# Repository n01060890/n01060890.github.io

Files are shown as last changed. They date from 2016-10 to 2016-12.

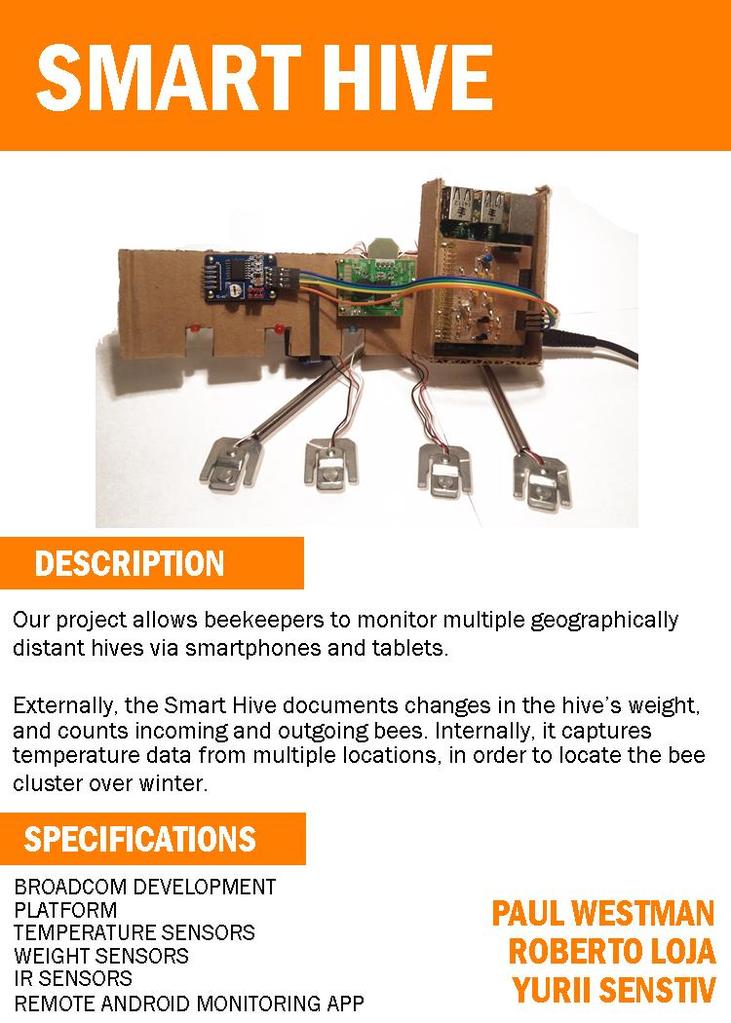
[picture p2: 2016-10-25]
media/placard.jpg

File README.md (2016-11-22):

# Smart Hive

Our project allows beekeepers to monitor multiple geographically distant hives via smartphones and tablets.

Externally, the Smart Hive documents changes in the hive's weight, and counts incoming and outgoing bees.
Internally, it captures multiple temperature and humidity data, in order to locate the bee cluster over the winter.

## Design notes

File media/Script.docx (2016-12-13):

30 Second Script

Name: Yurii Sentsiv

Project: Smart Hive

Date: December 13, 2016

In my project, Smart Hive, I was asked to implement features, that will give an ability to track internal temperature and humidity, as well as location of the bee cluster in the winter. With the help of multiple temperature and humidity sensors DHT11, and python program, I can retrieve the data. Further, the raw data is being processed, and is displayed graphically on the web server.

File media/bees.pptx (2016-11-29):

## Smart Hive

Yurii sentsiv
Ceng 317

## Introduction (Proposal)

- In the start of the semester my new team members and myself choose to work with bees, particularly create a monitoring system to help bee keepers in Humber College understand better and be able to see what is happening with the hives remotely.
- As have been discussed with bee keepers previously, it was clear that they were lacking the ability to have temperature/humidity status of the hive, as well as, having an ability to locate the bee cluster in the hive during the winter.
- In order to solve this problem I am using regular temperature & humidity sensors DHT11 in order to have real time readings, as well as, with help of the algorithm, to located cluster inside the hive, depending on the temperature readings.

## Introduction (Proposal)

- For more accurate readings I use 4 DHT11s on each side of the hive. Using the python script and Adafruit library I’m able to simultaneously read the data from all of the sensors using GPIO pins. Also, having the sensor hat, that was built by us, I have an LED, which I use to indicate when the data readings are happening.
- In order to have automated readings from the sensors, I use crontab, which is UNIX command that schedules the prewritten scripts.
- To have data visually presented, I’m using the javascript’s dygraph library to visually present the fluctuation of the temperature & humidity reading through the time.
- Also, to present the location of the cluster I use regular javascript’s canvas, where I draw the cluster, with the coordinates calculated with my algorithm.

## Budget

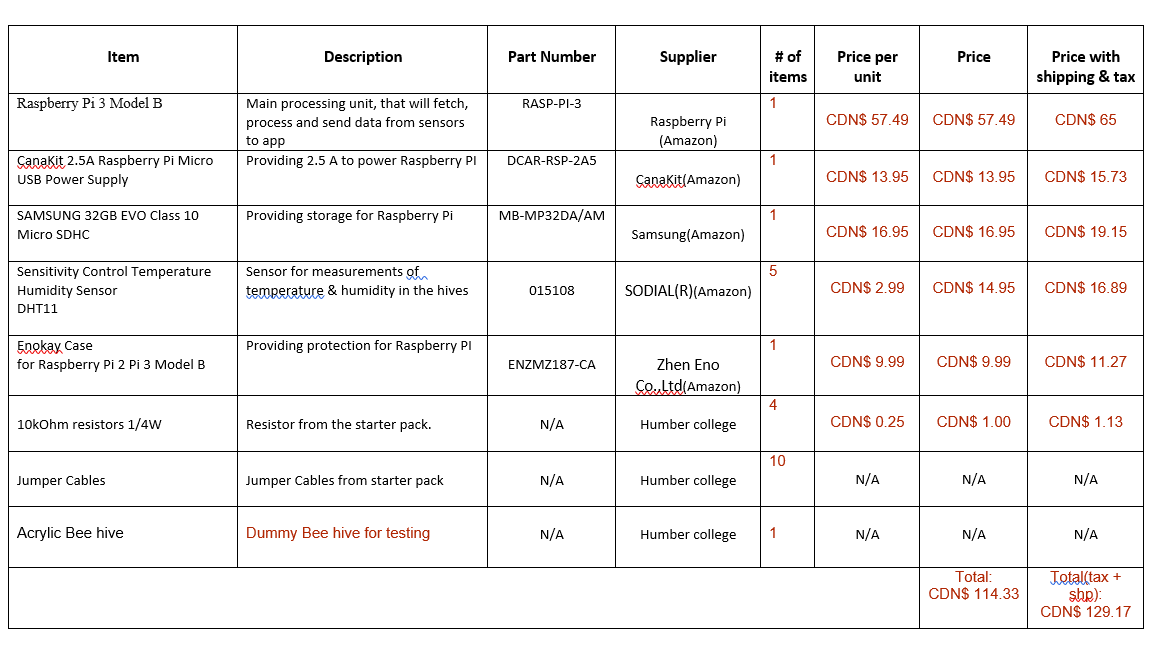
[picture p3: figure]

## Schedule : hardware

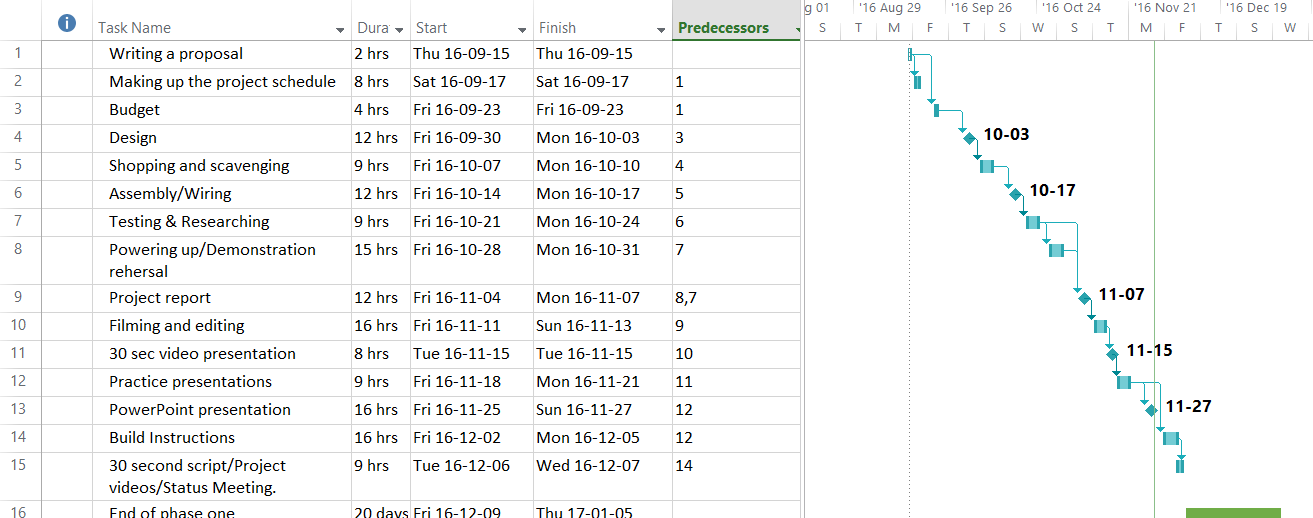
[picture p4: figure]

## Schedule : integration

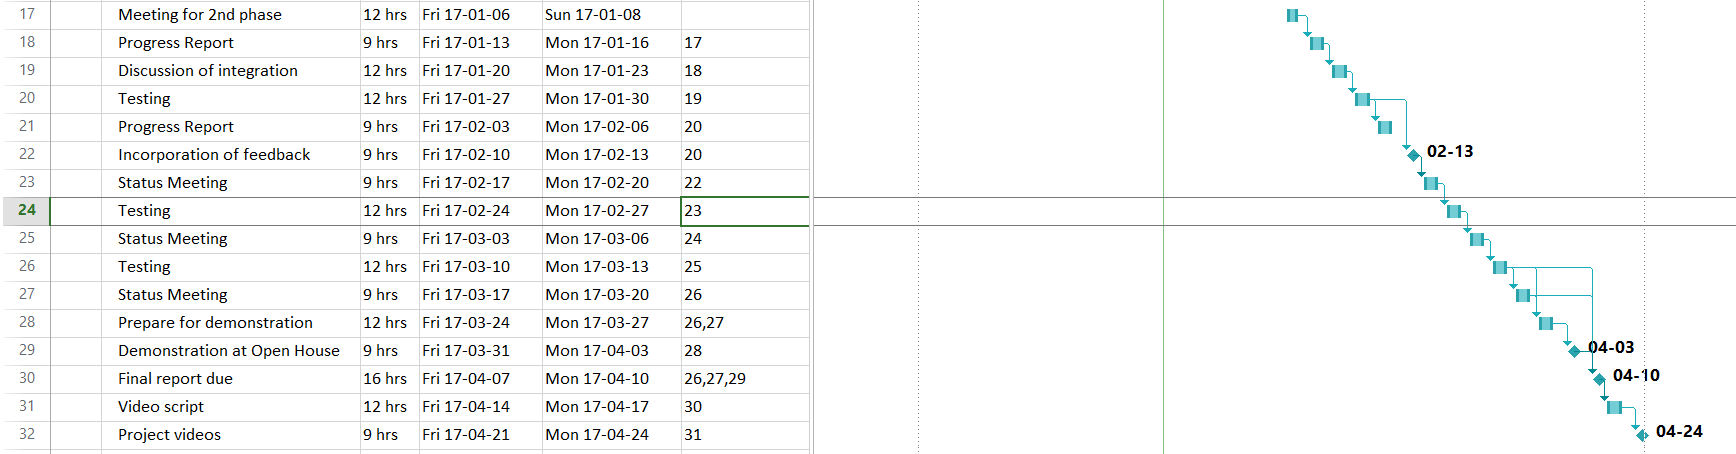
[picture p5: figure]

## Course knowledge utilized from previous courses

In the Computer Engineering Technology program we have learned about the following topics from the respective relevant courses:
- Construction of circuits from CENG 215 Digital And Interfacing Systems,
- Rapid application development and Gantt charts from CENG 216 Intro to Software Engineering,
- Micro computing from CENG 252 Embedded Systems,
- SQL from CENG 254 Database With Java,
- Web access of databases from CENG 256 Internet Scripting; and,
- Wireless protocols such as 802.11 from TECH152 Telecom Networks.

## Thank you!

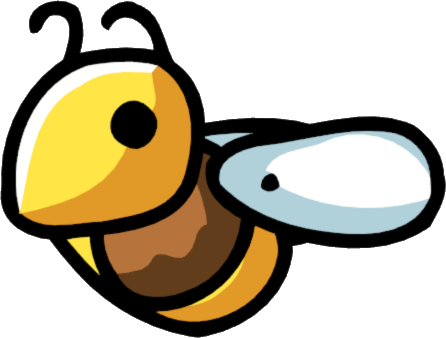
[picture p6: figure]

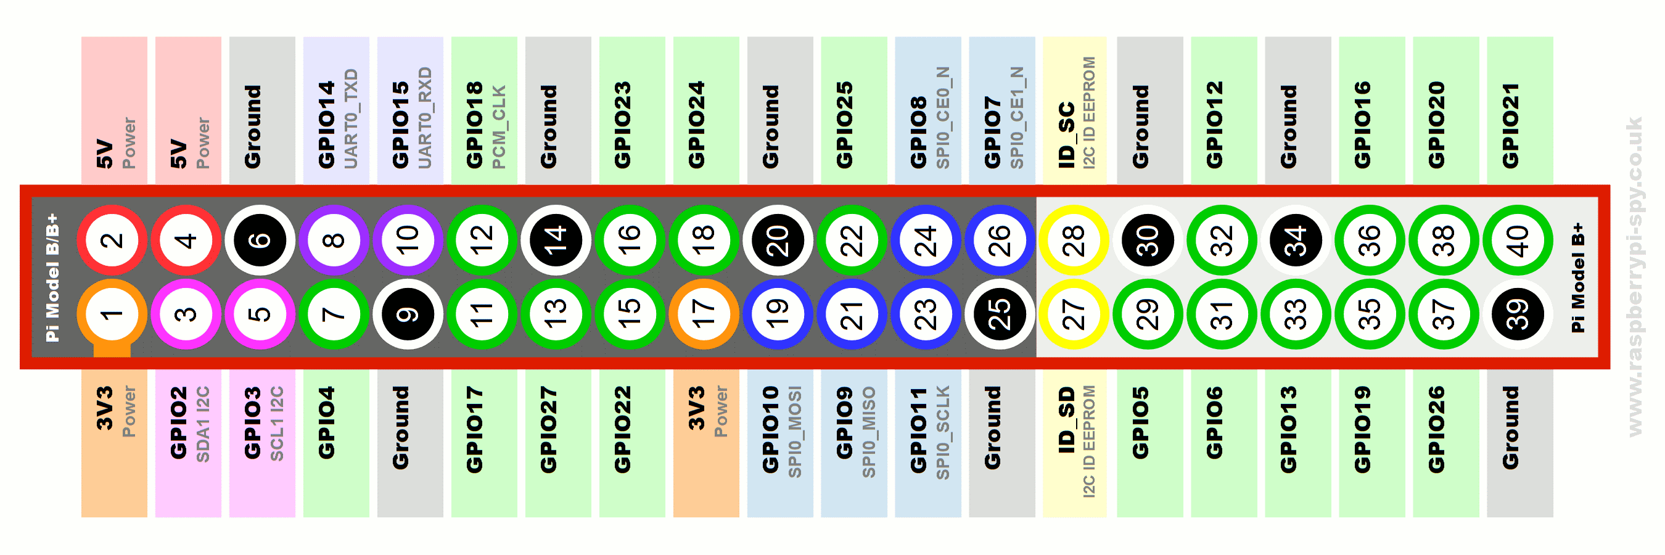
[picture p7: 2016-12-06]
media/rasp_pinout.png

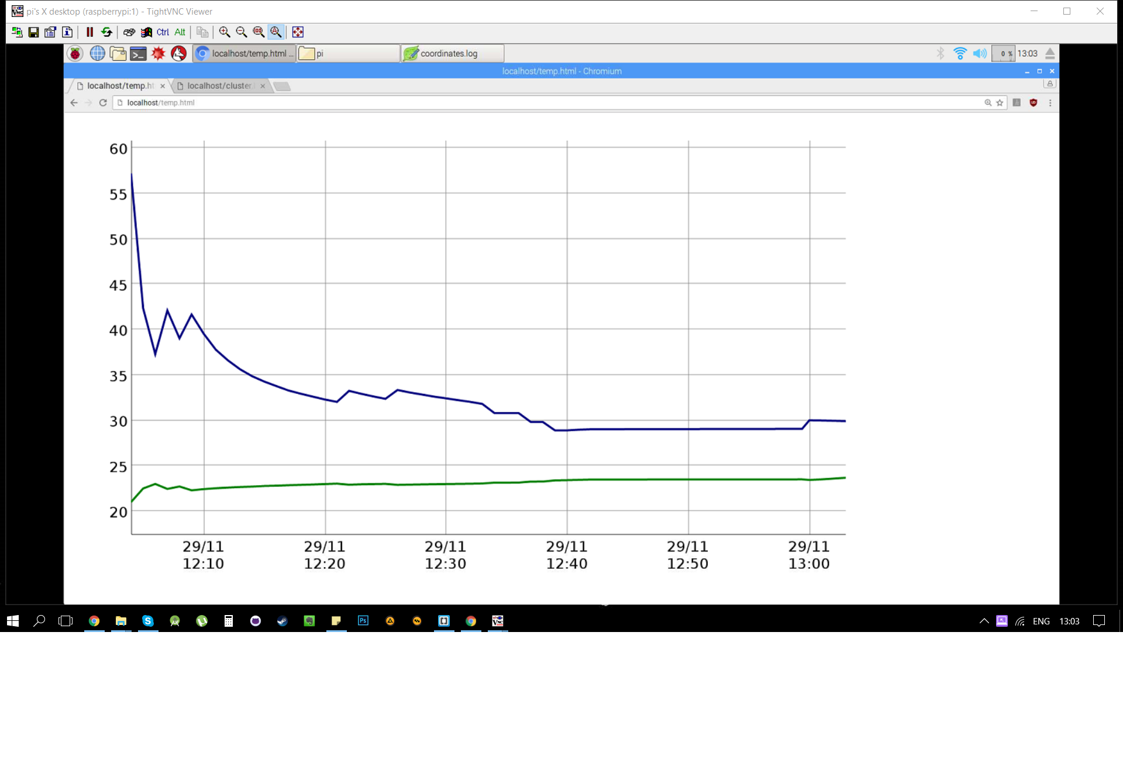
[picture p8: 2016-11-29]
media/graph.png

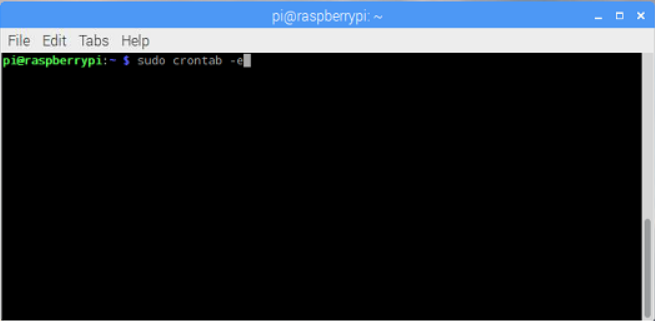
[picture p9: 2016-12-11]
media/crontab-call.png

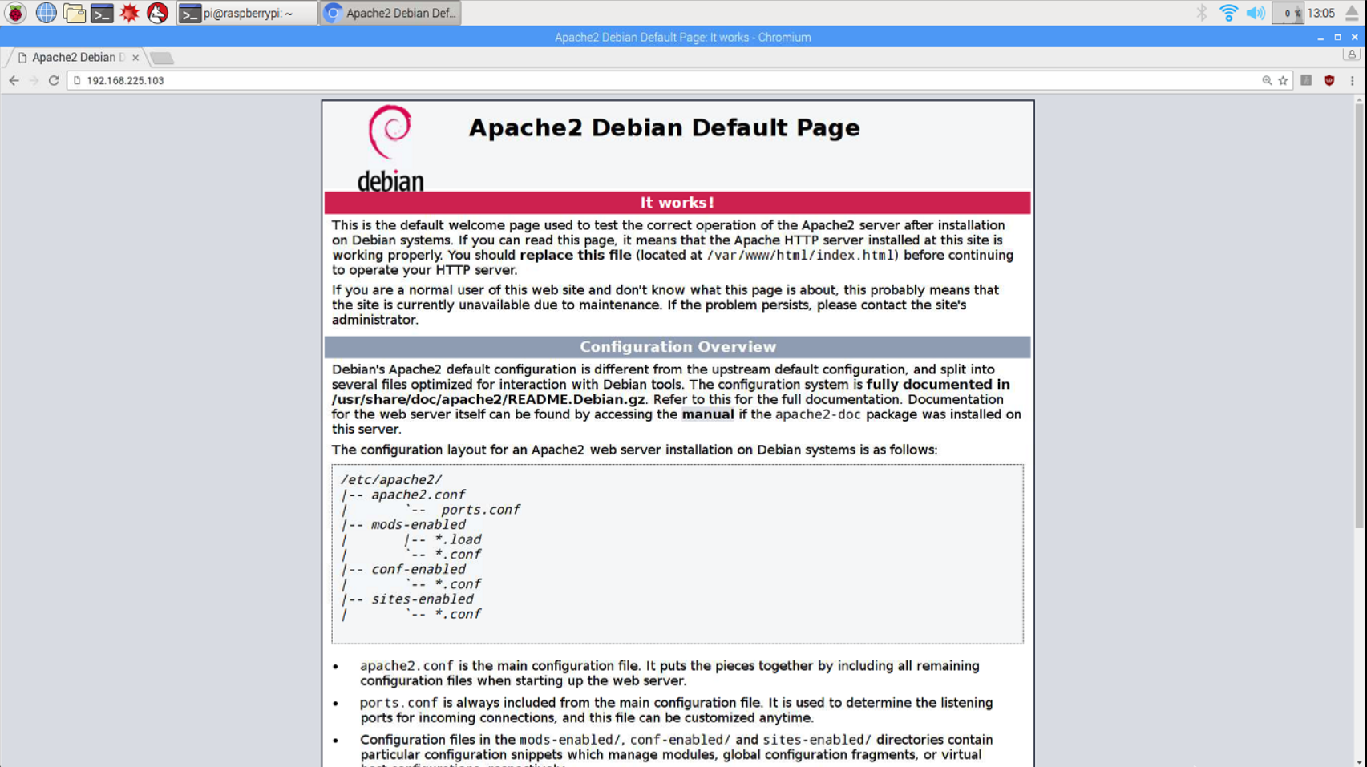
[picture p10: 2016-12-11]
media/apache.png

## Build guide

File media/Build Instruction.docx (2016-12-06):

Smart Hive

Build Log

By Yurii Sentsiv

Introduction

The project that I was working is the part of the automated hive monitoring system, called Smart Hive. My group, called “2bee || !2bee”, consisting of Paul Westman, Roberto Loja, and Yurii Sentsiv(myself) designed a prototype of Smart Hive, that would gather different information on hives, where our smart system would be installed. Specifically, I was working on temperature and humidity monitoring, as well as bee cluster detection. Here I would like to share my achievement, as well as my progress, so everyone could rebuild my project.

System Diagram

The concept of our project is to give an ability remotely track the status of the hives. It will be achieved to fetching the sensor readings from the hives, that would be attached to Raspberry Pi, process them, save in the database, and then deliver to customers in the user-friendly Android application representation.

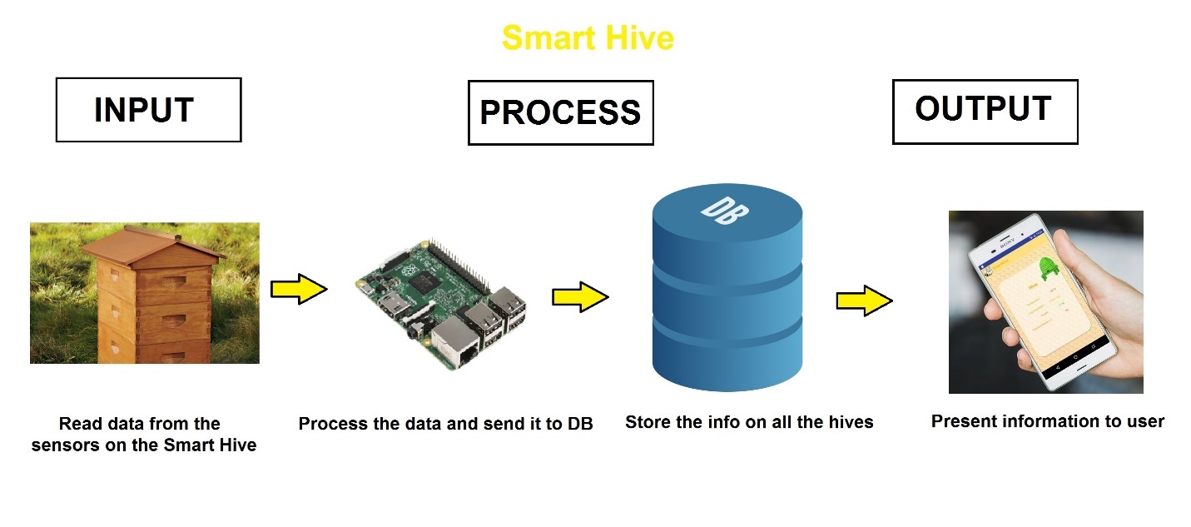
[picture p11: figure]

Budget of the Project

As it was decided in my group, different parts of the project would be covered by different group member, as it will result it total group budget, decreasing total cost, as well as on time of research given to different parts of the Smart Hive project. I ended up using Raspberry PI, DHT11 temperature/humidity sensors, as well as resistors, jumper cables, electrical tape, soldering iron, Humber PCB Components Kit, and making laser cut dummy hive. Fortunately, most of the parts I obtained in kit, that I used in my previous courses, as well as laser cut hive, that to presented to me for free. Following is my budget:


Time Commitment

At the start of our semester we created schedule for better time management, and tried to follow all the milestones in time. If exclude all the progress reports, meetings and designing, here are the key point that need to be done, in order for anyone to replicate the project:

Milestone Time required

Ordering parts May vary where you order them, but if you would choose to guy them in the Canada Robotix, you can get them in few hours.

Laser Cutting the acrylic hive 10 minutes

Printing PCB 1 day

Soldering & testing PCB 3 hours

Soldering the sensor to wires and resistor 30 minutes

Attaching the sensor on the hive 5 minutes

Attaching the sensors on the PI’s GPIOs 10 minutes

Raspberry Pi 3 Setup 2 hours

Loading the code and executing it 10 minutes

Unit testing 30 minutes

Setting up the Apache server 30 minutes

Loading the HTML & JavaScript

For data representation 10 minutes

The whole process should take around 2-3 days, if the appropriate tools are accessible (PCB print, laser cutter, soldering station). For myself the whole process was split into 15 weeks, where every week I committed few hours, in order to be on track and be able to finish everything by the week 15. Attached is the original project schedule:

Mechanical Assembly

Step 1:

Create the casing for the dummy hive, in my case I was using Corel Draw. For our laser cutting machine, specific colours specified the inside cut → red, outside cut → green, engraving → black. Attached is my casing that consist of 4 part, which I have glued afterwards.

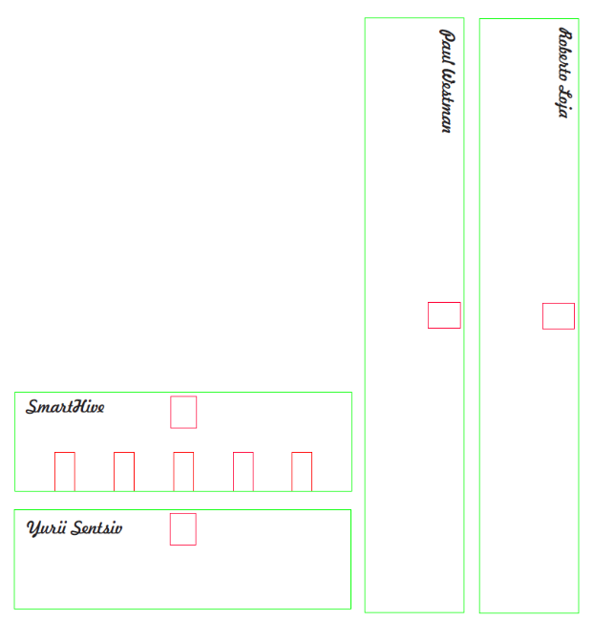
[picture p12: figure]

Step 2:

In my case, because I bought DHT11 sensors without PCB board with resistors, that sensor needs, I simply soldered the resistors to the sensors between Power(Pin1) & Data(Pin2), so I didn’t need to use the breadboard, which was used in development purposes.

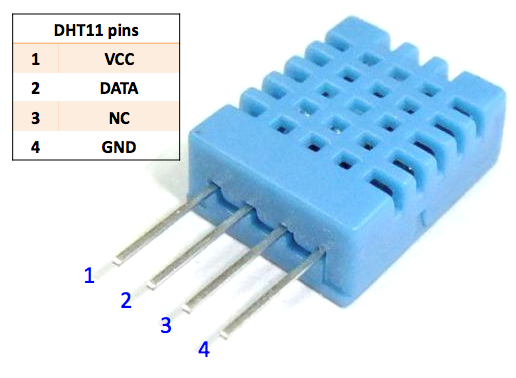
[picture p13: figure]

If it is possible, I recommend you to buy the one with the PCB.

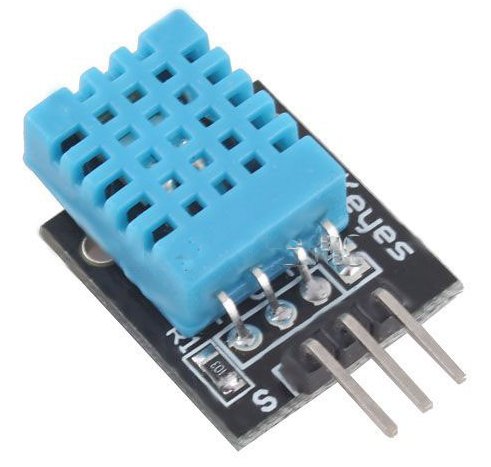
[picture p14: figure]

Step 3:

In this next step, we will be connecting the sensors to the Raspberry Pi. In my case I was struggling to connect multiple sensors, as in the most example of code, this particular sensor was using GPIO4, which is also GPCLK0. All other GPIO pins would not work with this particular code in C, nor with Python equivalent:

#include <wiringPi.h>

#include <stdio.h>

#include <stdlib.h>

#include <stdint.h>

#define MAXTIMINGS 85

#define DHTPIN 7

int dht11_dat[5] = { 0, 0, 0, 0, 0 };

void read_dht11_dat()

{

uint8_t laststate = HIGH;

uint8_t counter = 0;

uint8_t j = 0, i;

float f;

dht11_dat[0] = dht11_dat[1] = dht11_dat[2] = dht11_dat[3] = dht11_dat[4] = 0;

pinMode( DHTPIN, OUTPUT );

digitalWrite( DHTPIN, LOW );

delay( 18 );

digitalWrite( DHTPIN, HIGH );

delayMicroseconds( 40 );

pinMode( DHTPIN, INPUT );

for ( i = 0; i < MAXTIMINGS; i++ )

{

counter = 0;

while ( digitalRead( DHTPIN ) == laststate )

{

counter++;

delayMicroseconds( 1 );

if ( counter == 255 )

{

break;

}

}

laststate = digitalRead( DHTPIN );

if ( counter == 255 )

break;

if ( (i >= 4) && (i % 2 == 0) )

{

dht11_dat[j / 8] <<= 1;

if ( counter > 16 )

dht11_dat[j / 8] |= 1;

j++;

}

}

if ( (j >= 40) &&

(dht11_dat[4] == ( (dht11_dat[0] + dht11_dat[1] + dht11_dat[2] + dht11_dat[3]) & 0xFF) ) )

{

f = dht11_dat[2] * 9. / 5. + 32;

printf( "Humidity = %d.%d %% Temperature = %d.%d C (%.1f F)\n",

dht11_dat[0], dht11_dat[1], dht11_dat[2], dht11_dat[3], f );

}else {

printf( "Data not good, skip\n" );

}

}

int main( void )

{

printf( "Raspberry Pi wiringPi DHT11 Temperature test program\n" );

if ( wiringPiSetup() == -1 )

exit( 1 );

while ( 1 )

{

read_dht11_dat();

delay( 1000 );

}

return(0);

}

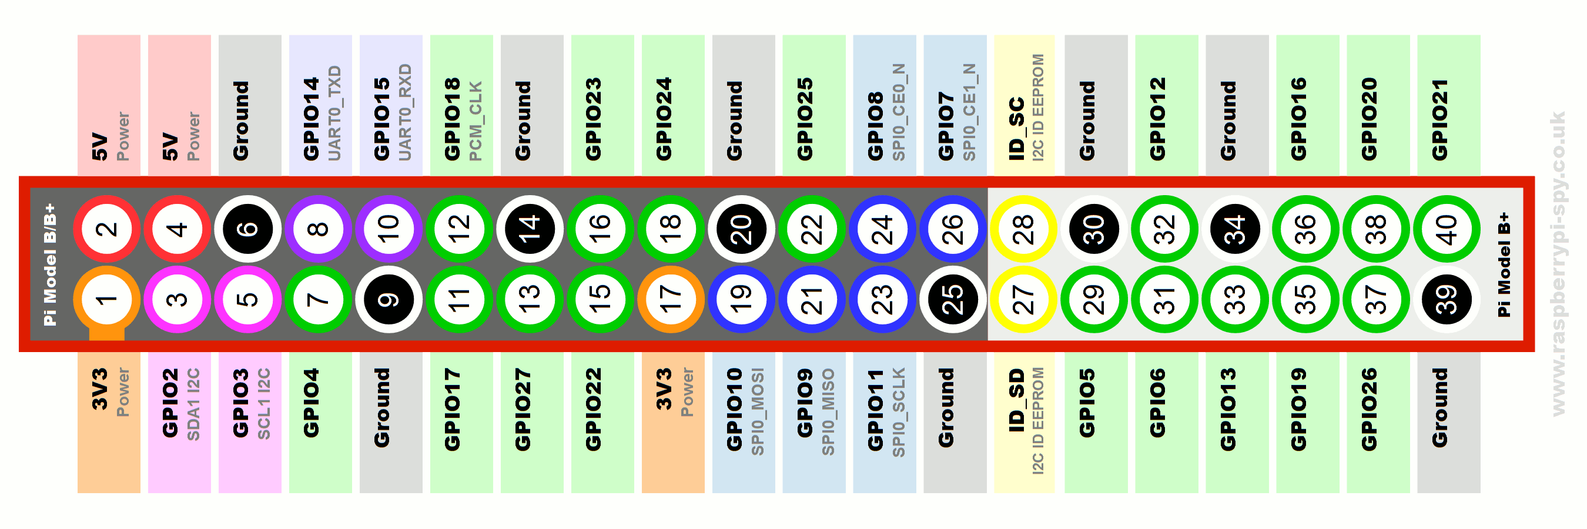
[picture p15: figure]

Instead I found Adafruit library that handles the DHT11 on the regular GPIO pins, so consequently I used GPIO22 – GPIO25 for 4 sensors. → https://github.com/adafruit/Adafruit_Python_DHT . Instruction on install are in the README of that Git project.

The following is the wiring that I used to connect my DHT11 to Raspberry PI’s GPIO 22-25 pins.

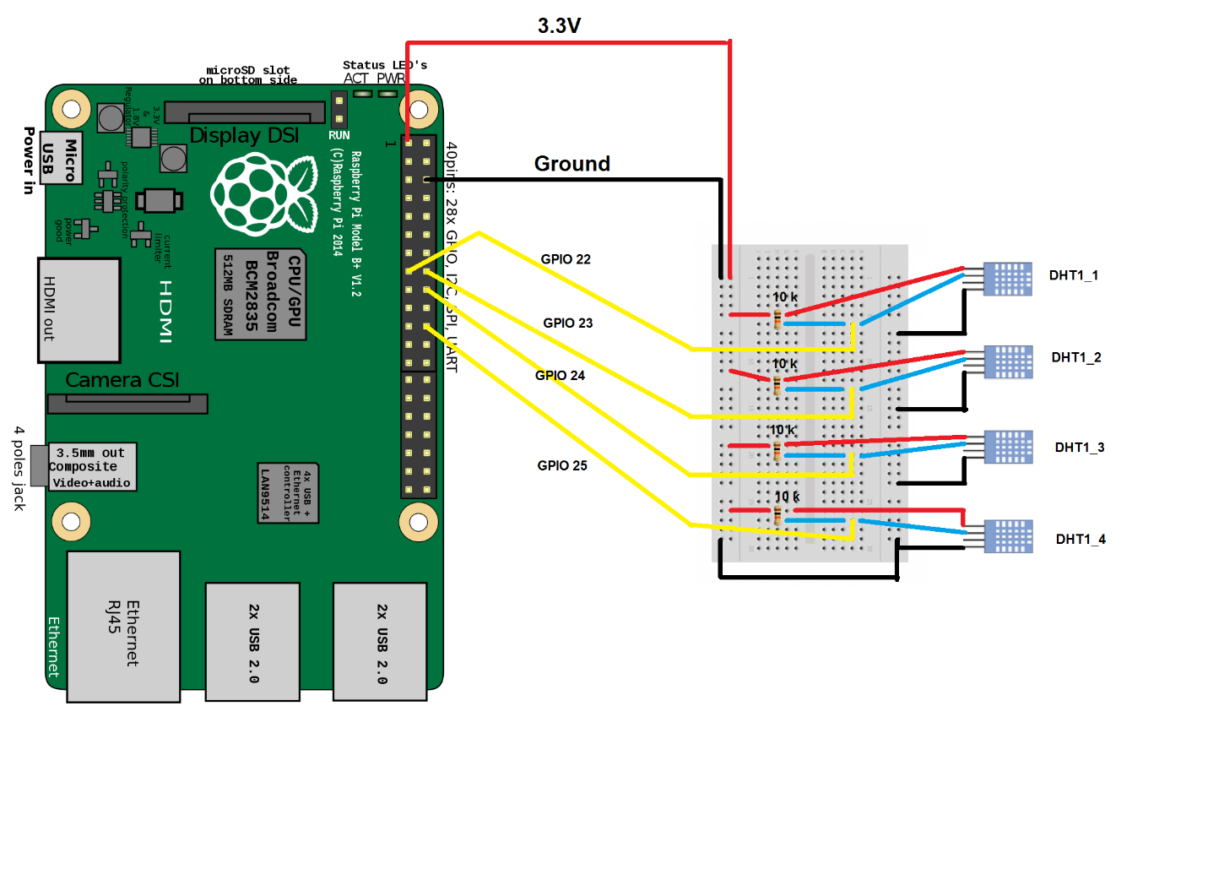
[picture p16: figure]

As I said previously, you don’t need to have a resistor, if you’ll get the sensor with the PCS. In my case had it soldered and isolated with the electrical tape.

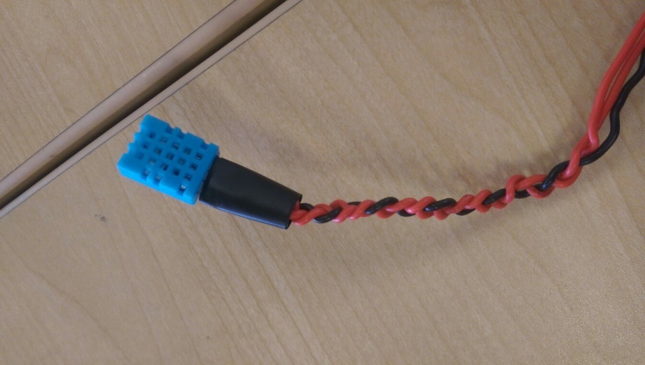
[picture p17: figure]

PCB / Soldering

As was mentioned before I used the PCB that was provided by Humber College. The EAGLE software was used in order to draw it. We received freshly printed PCBs and had to solder all of the components on them. In my project, I used the LED mounted on top of the PCB in order to indicate when data from sensors is being read. Following are the schematics and board for PCB.

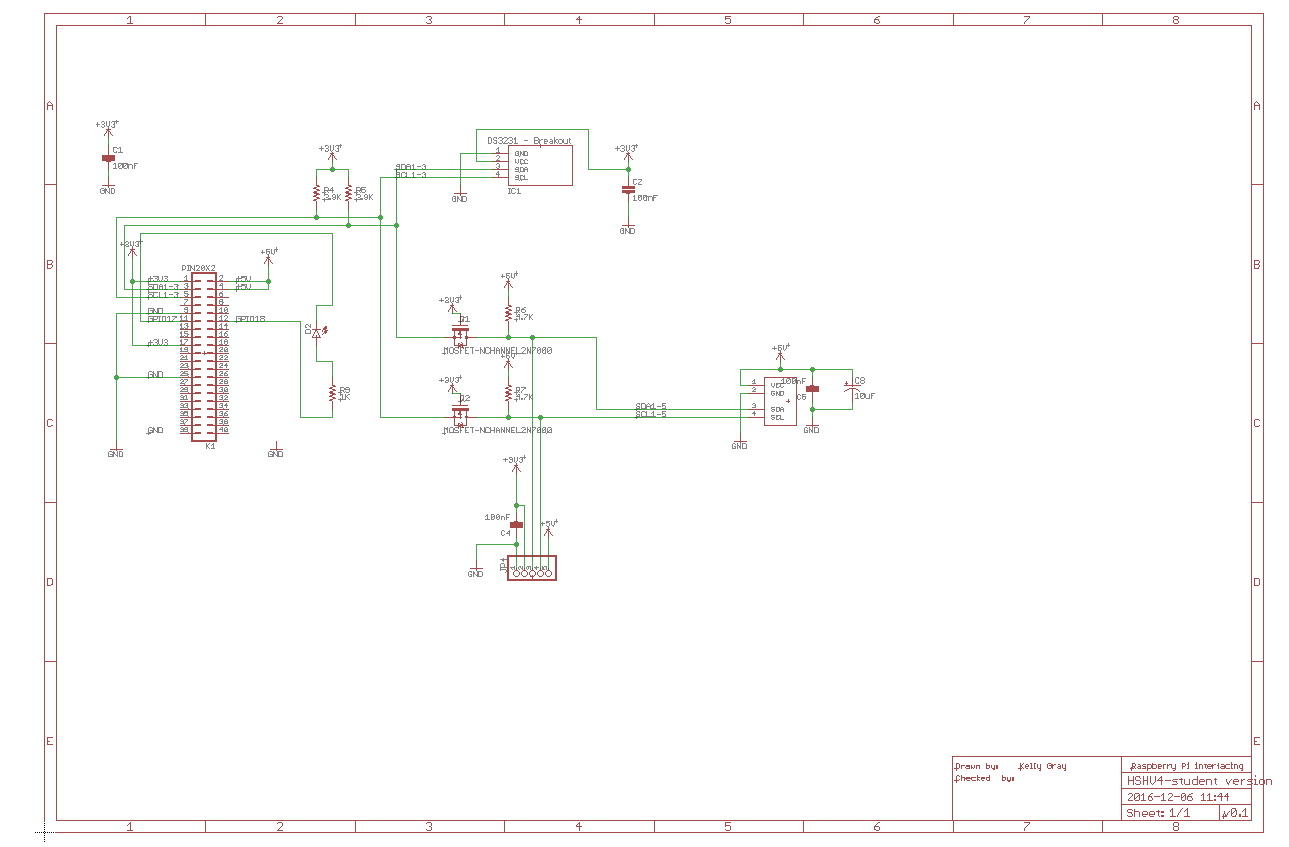
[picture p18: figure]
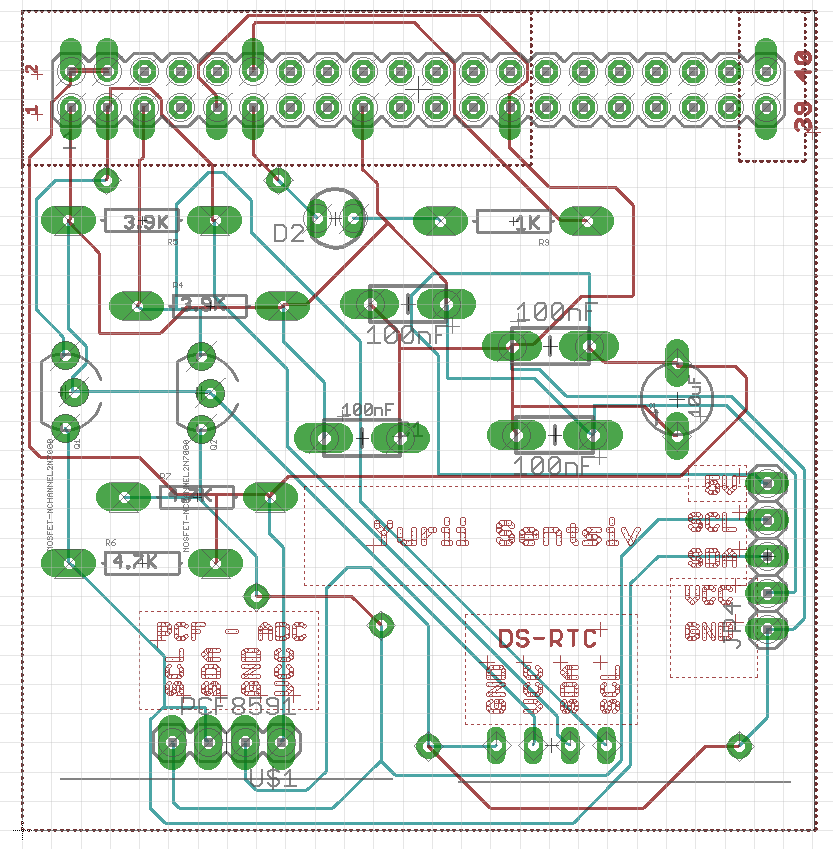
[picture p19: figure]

I also tried to print my custom PCB in order to recreate the PCB of the DHT11, but I had issues with soldering it, as the plates for the components were too tiny to be properly soldered. Following if the schematics and board for it.

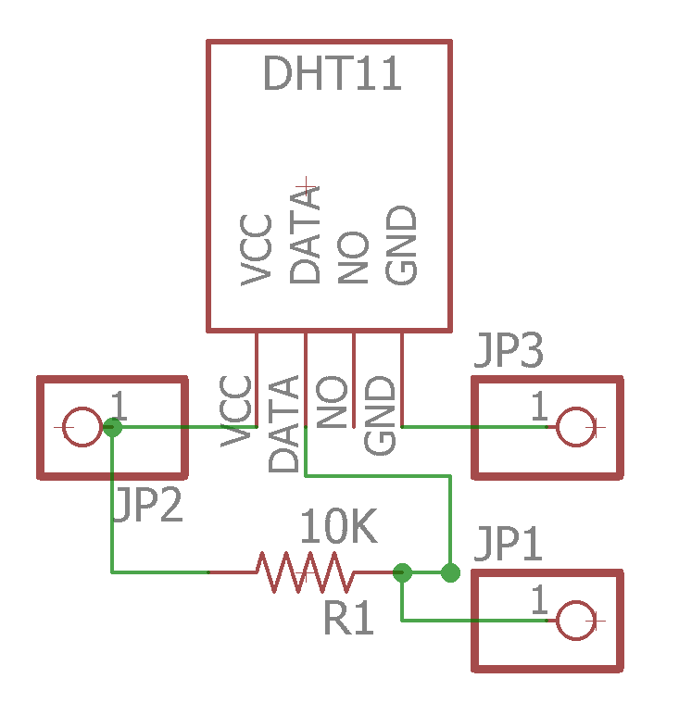
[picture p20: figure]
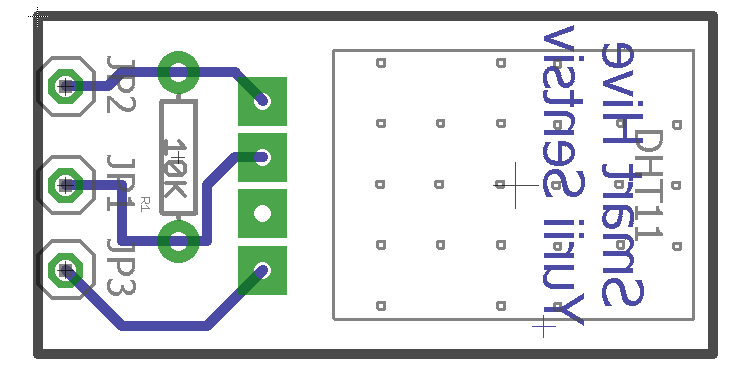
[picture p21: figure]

Power Up

Now, when all of the wiring are done, we can use the Python code in order to read the data. The following is the code that initializes the GPIO pins 22-25 and tries to read the data from them. In case of success, the “1.c” program gets called, which will light up the LED on the PCB green, indicating that the data read was successful. But, if there were any issues, the “2.c” program is going to be called, which will light red.

#!/usr/bin/python

# Copyright (c) 2014 Adafruit Industries

# Author: Tony DiCola

# Permission is hereby granted, free of charge, to any person obtaining a copy

# of this software and associated documentation files (the "Software"), to deal

# in the Software without restriction, including without limitation the rights

# to use, copy, modify, merge, publish, distribute, sublicense, and/or sell

# copies of the Software, and to permit persons to whom the Software is

# furnished to do so, subject to the following conditions:

# The above copyright notice and this permission notice shall be included in all

# copies or substantial portions of the Software.

# THE SOFTWARE IS PROVIDED "AS IS", WITHOUT WARRANTY OF ANY KIND, EXPRESS OR

# IMPLIED, INCLUDING BUT NOT LIMITED TO THE WARRANTIES OF MERCHANTABILITY,

# FITNESS FOR A PARTICULAR PURPOSE AND NONINFRINGEMENT. IN NO EVENT SHALL THE

# AUTHORS OR COPYRIGHT HOLDERS BE LIABLE FOR ANY CLAIM, DAMAGES OR OTHER

# LIABILITY, WHETHER IN AN ACTION OF CONTRACT, TORT OR OTHERWISE, ARISING FROM,

# OUT OF OR IN CONNECTION WITH THE SOFTWARE OR THE USE OR OTHER DEALINGS IN THE

# SOFTWARE.

import Adafruit_DHT

from subprocess import call

# Sensor should be set to Adafruit_DHT.DHT11,

# Adafruit_DHT.DHT22, or Adafruit_DHT.AM2302.

sensor = Adafruit_DHT.DHT11

# Example using a Beaglebone Black with DHT sensor

# connected to pin P8_11.

#pin = 'P8_11'

# Example using a Raspberry Pi with DHT sensor

# connected to GPIO23.

pin1 = 22

pin2 = 23

pin3 = 24

pin4 = 25

# Try to grab a sensor reading. Use the read_retry method which will retry up

# to 15 times to get a sensor reading (waiting 2 seconds between each retry).

humidity1, temperature1 = Adafruit_DHT.read_retry(sensor, pin1)

humidity2, temperature2 = Adafruit_DHT.read_retry(sensor, pin2)

humidity3, temperature3 = Adafruit_DHT.read_retry(sensor, pin3)

humidity4, temperature4 = Adafruit_DHT.read_retry(sensor, pin4)

# Note that sometimes you won't get a reading and

# the results will be null (because Linux can't

# guarantee the timing of calls to read the sensor).

# If this happens try again!

if humidity1 is not None and temperature1 is not None:

print('1st: Temp={0:0.1f}*C Humidity={1:0.1f}%'.format(temperature1, humidity1))

call(["./1"])

else:

print('Failed to get first readings. Try again!')

call(["./2"])

if humidity2 is not None and temperature2 is not None:

print('2nd: Temp={0:0.1f}*C Humidity={1:0.1f}%'.format(temperature2, humidity2))

call(["./1"])

else:

print('Failed to get second readings. Try again!')

call(["./2"])

if humidity3 is not None and temperature3 is not None:

print('3rd: Temp={0:0.1f}*C Humidity={1:0.1f}%'.format(temperature3, humidity3))

call(["./1"])

else:

print('Failed to get third readings. Try again!')

call(["./2"])

if humidity4 is not None and temperature4 is not None:

print('4th: Temp={0:0.1f}*C Humidity={1:0.1f}%'.format(temperature4, humidity4))

call(["./1"])

else:

print('Failed to get fourth readings. Try again!')

call(["./2"])

1.c

#include <stdio.h>

#include <stdlib.h>

#include <stdint.h>

#include <wiringPi.h>

int main (void)

{

int i = 0;

if (wiringPiSetup () == -1)

exit (1) ;

//printf ("Success\n") ;

pinMode (0, OUTPUT) ;

pinMode (1, PWM_OUTPUT) ;

for (i = 0; i < 1; i++)

{

digitalWrite (0, LOW) ;

pwmWrite (1, 1023) ;

delay (500);

digitalWrite (0, LOW) ;

pwmWrite (1, 0) ;

delay (500);

}

return 0 ;

}

2.c

#include <stdio.h>

#include <stdlib.h>

#include <stdint.h>

#include <wiringPi.h>

int main (void)

{

int i = 0;

if (wiringPiSetup () == -1)

exit (1) ;

//printf ("Fail\n") ;

pinMode (0, OUTPUT) ;

pinMode (1, PWM_OUTPUT) ;

for (i = 0; i < 1; i++)

{

digitalWrite (0, HIGH);

pwmWrite (1, 0) ;

delay (500);

digitalWrite (0, LOW) ;

pwmWrite (1, 0) ;

delay (500);

}

return 0 ;

}

Unit Testing

If the set up steps will be followed, then the following result should be expected:

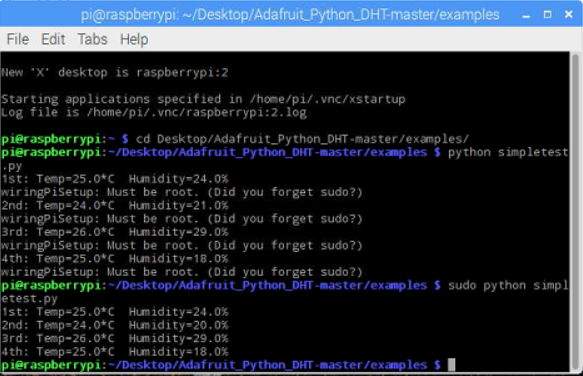
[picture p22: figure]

If you don’t have the PCB with the LED, it’s ok, the program will still work. With Adafruit library we can use any GPIO pin. In case if any of the sensor isn’t operating properly, the program will take longer time to execute, as it will try to access the sensor few times. If thank was unsuccessful, then the message will appear, that will inform user that there a problem with particular sensor.

Production Testing

Now, if you were able to successfully retrieve the data from the sensors, and build your PCB, you can see that when ever the readings are being made through the Python program, the C program is being called, in order to indicate user that the readings were successful or not.

Reproducibility Based on Instructions

At this point, after all of the explanations have been made, anyone with the access to appropriate tools should be able to reproduce it.

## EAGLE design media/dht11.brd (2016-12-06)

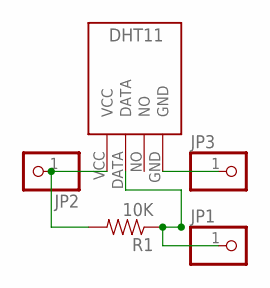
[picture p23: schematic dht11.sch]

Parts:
JP1, JP2, JP3: PINHD-1X1; 1X01
R1: 10K; AXIAL-0.3
U$1: DHT11

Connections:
unnamed: JP3.1, U$1.GND
unnamed: JP2.1, R1.P$2 (2), U$1.VCC
unnamed: JP1.1, R1.P$1 (1), U$1.DATA

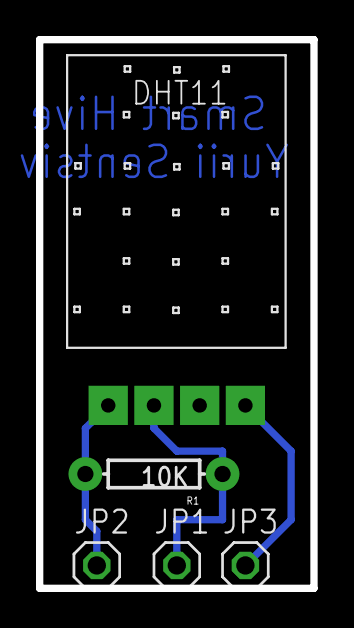
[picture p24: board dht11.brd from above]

Board: 2 copper layers, 15.2 x 30.5 mm, 5 parts (0 on the bottom side), 3 nets.

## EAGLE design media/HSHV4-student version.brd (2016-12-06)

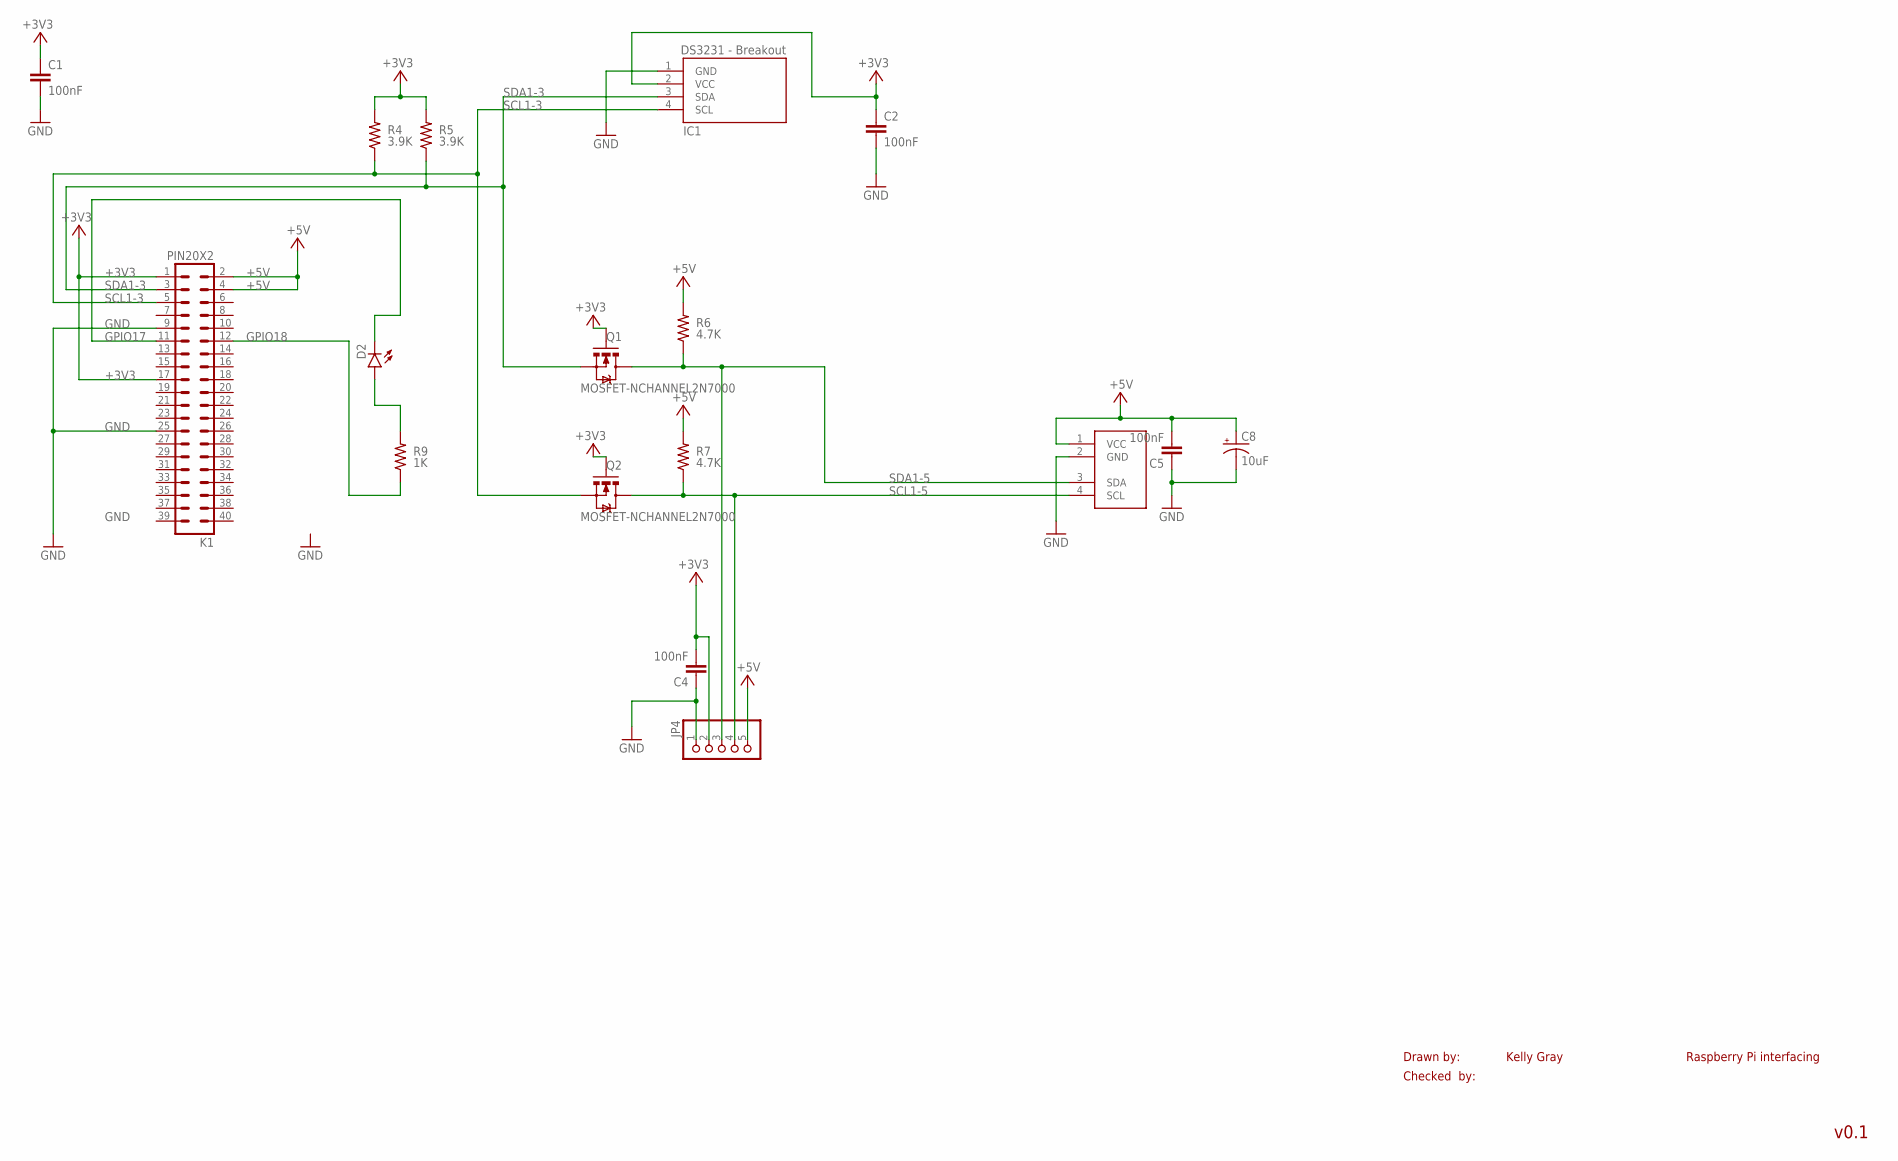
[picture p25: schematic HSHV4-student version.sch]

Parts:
C1, C2, C4, C5: 100nF; CAP-PTH-SMALL-KIT
C8: 10uF; CPOL-RADIAL-10UF-25V
D2: LED-3MM-NO_SILK; LED3MM-NS
IC1: DS3231; 8PTH
JP4: PINHD-1X5; 1X05
K1: PIN20X2; PIN_20X2
Q1, Q2: MOSFET-NCHANNEL2N7000; TO-92
R4, R5: 3.9K; AXIAL-0.3; TOLERANCE 5%
R6, R7: 4.7K; AXIAL-0.3; TOLERANCE 5%
R9: 1K; AXIAL-0.3; TOLERANCE 5%
U$1: PCF8591; 1X04

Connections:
+3V3: C1.1, C2.1, C4.2, IC1.2 (VCC), JP4.2, K1.1, K1.17, Q1.2 (G), Q2.2 (G), R4.P$2 (2), R5.P$2 (2)
+5V: C5.2, C8.1 (+), JP4.5, K1.2, K1.4, R6.P$2 (2), R7.P$2 (2), U$1.1 (VCC)
GND: C1.2, C2.2, C4.1, C5.1, C8.2 (-), IC1.1 (GND), JP4.1, K1.9, K1.25, U$1.2 (GND)
GPIO17: D2.K (C), K1.11
GPIO18: K1.12, R9.P$1 (1)
unnamed: D2.A, R9.P$2 (2)
SCL1-3: IC1.4 (SCL), K1.5, Q2.1 (S), R4.P$1 (1)
SCL1-5: JP4.4, Q2.3 (D), R7.P$1 (1), U$1.4 (SCL)
SDA1-3: IC1.3 (SDA), K1.3, Q1.1 (S), R5.P$1 (1)
SDA1-5: JP4.3, Q1.3 (D), R6.P$1 (1), U$1.3 (SDA)

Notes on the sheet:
Drawn by:
Checked by:
Kelly Gray
v0.1
Raspberry Pi interfacing

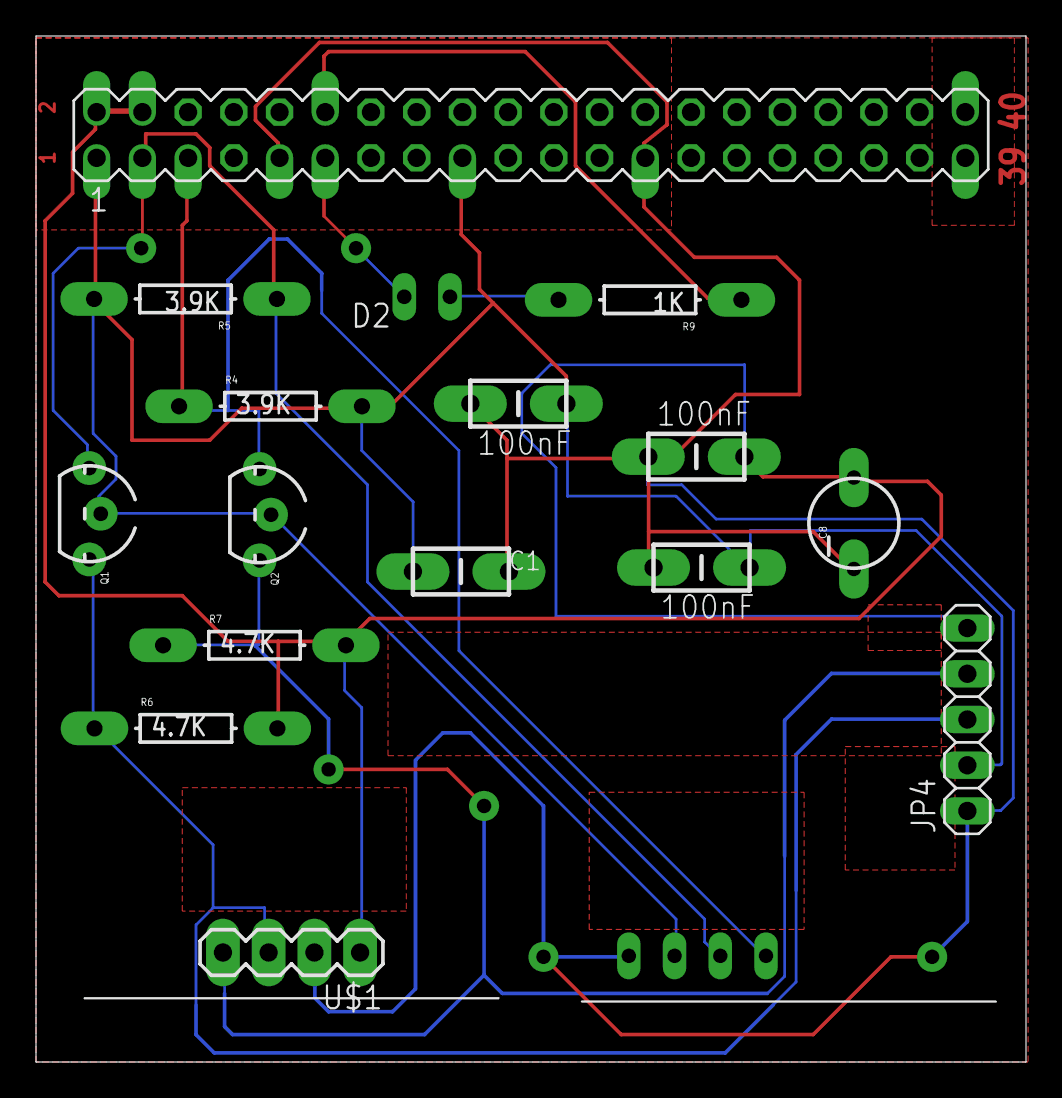
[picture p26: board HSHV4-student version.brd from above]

Board: 2 copper layers, 55.0 x 57.0 mm, 17 parts (0 on the bottom side), 10 nets.

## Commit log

2016-11-15 Adding code
    Current code that I've used to get readings and display them into graph.
2016-12-06 Build Log
    Added Build Log page
    [HSHV4-student version.brd, HSHV4-student version.sch, dht11.brd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]

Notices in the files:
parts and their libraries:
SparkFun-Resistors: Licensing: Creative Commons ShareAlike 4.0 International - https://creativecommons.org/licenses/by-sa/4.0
